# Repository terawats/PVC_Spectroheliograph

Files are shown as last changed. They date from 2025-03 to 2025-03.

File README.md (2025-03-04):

# PVC Spectroheliograph(SHG)
This is a projects for Solar spectroheliograph form PVC tube and 3D print parts. Optical devives also required as well.
See sample image of Sun on Hydrogen Alpha (Ha) taken by this devices as below.
Ha_20250303_Negative_colorized
Image of sun in Hydrogen Alpha (Ha) 

## Setup condition
Below is a setup condition and equipemnt for this project.
IMG_1616 HEIC_compressed
Image of equipment when taken a solar

## Lists of devices
1. 2" PVC Y Connector(1.5USD)                                1pcs
2. 3D print parts form project SLT files                     4pcs    
3. Pentax camera lens 135mm F/3.5 M42 mount (15USD)          2pcs
4. 49mm UV/IR filter (use only frame, 1.5USD)                2pcs
5. Worm screw (0.4USD)                                       6pcs
6. Gratting 2,400Line/mm 30x30mm (70-80USD)                  1pcs
7. Glass slit 7um width 13mm long (70-80USD)                 1pcs
8. Manual sliding table 60mm RS60-L (25USD)                  1pcs
9. Copper disk 40mm diameter 2mm thikness (1.5USD)           1pcs
10. Copper disk 25mm diameter 1mm thikness (1USD)            1pcs
11. M42x1.0 to M42x0.75 adapter ring (8USD)                  2pcs
12. M42 Extension tube (5-15USD)                             3pcs
13. M42 F to F adapter (7-10USD)                             1pcs
14. M42 to 1.25" adapter for cmos camear mount (10USD)       1pcs
15. IMX678 Mono CMOS Camera (180-200USD)                     1pcs

Note: price are estimated for refferance only.

## SHG assembly
IMG_1507 HEIC_compressed

IMG_1514 HEIC_compressed

IMG_1505 HEIC_compressed

IMG_1520 HEIC_compressed

IMG_1532 HEIC_compressed

IMG_1525 HEIC_compressed

IMG_1524 HEIC_compressed

IMG_1535 HEIC_compressed

IMG_1533 HEIC_compressed

Slit assy

IMG_1548 HEIC_compressed

IMG_1647 HEIC_compressed

IMG_1649 HEIC_compressed

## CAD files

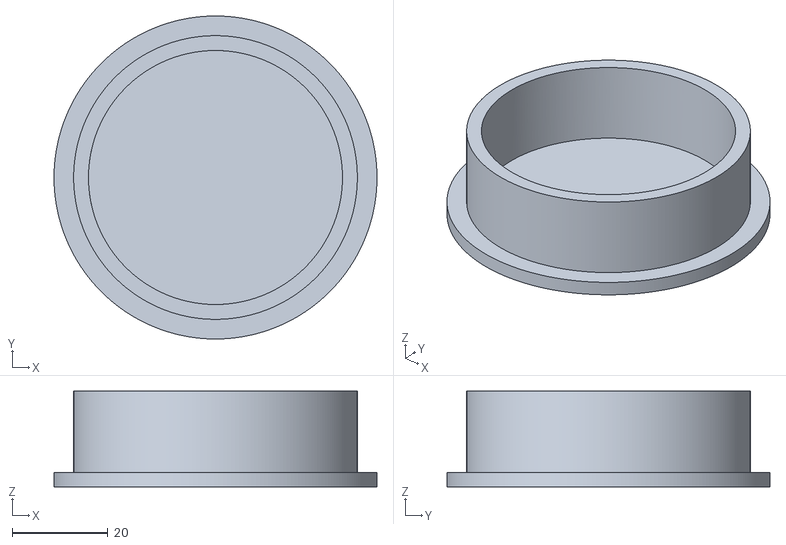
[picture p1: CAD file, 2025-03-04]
PVC SHG tube cover.stl
67.4 x 67.4 x 20.0

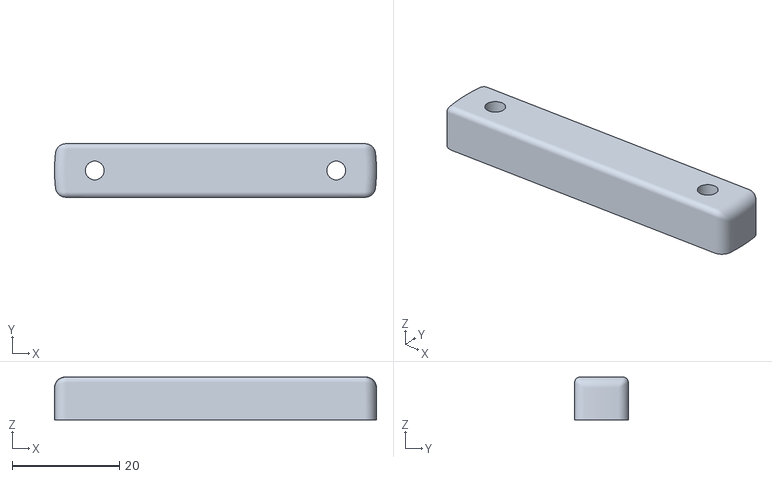
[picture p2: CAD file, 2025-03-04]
PVC SHG calipper bar.stl
60.0 x 10.0 x 8.00

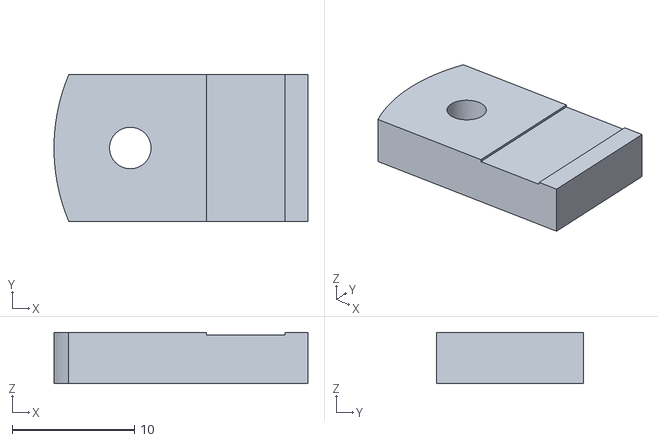
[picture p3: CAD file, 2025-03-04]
PVC SHG gratting cover.stl
20.8 x 12.0 x 4.20

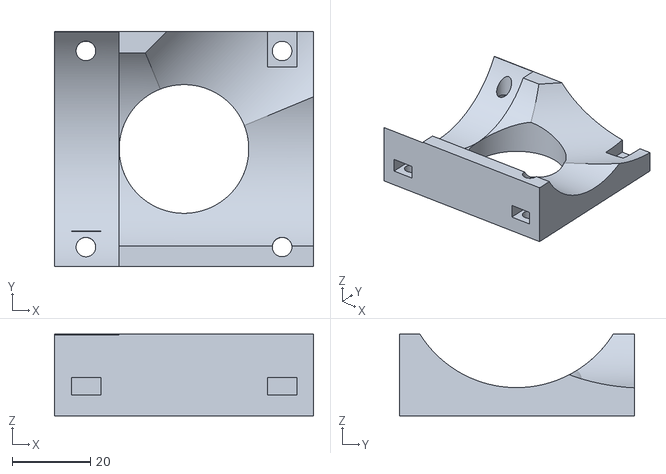
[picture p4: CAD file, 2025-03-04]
PVC SHG calipper mount.stl
66.0 x 59.9 x 20.8

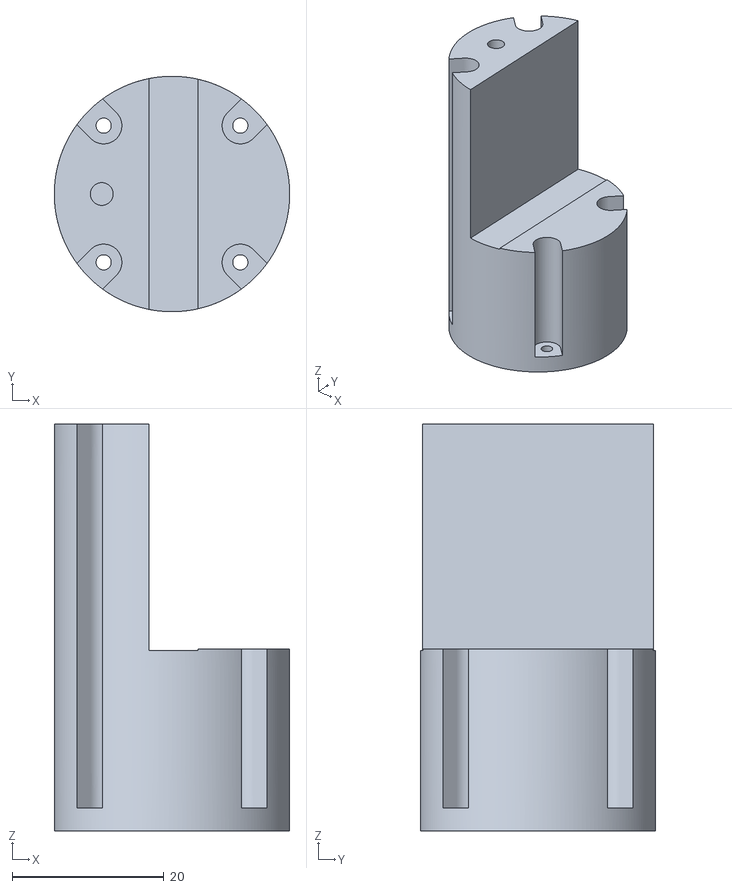
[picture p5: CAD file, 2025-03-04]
PVC SHG gratting mount.stl
31.0 x 31.0 x 53.6
